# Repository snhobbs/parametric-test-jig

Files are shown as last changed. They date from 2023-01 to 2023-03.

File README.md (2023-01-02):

# parametric-test-jig

*Parameterized OpenSCAD projects allowing single command generation of probe stations.*

## Purpose & Philosophy
Probe stations typically have many parts that need to line up exactly with several different parts.
+ PCB under test pads must line up with the probes
+ Probes must lineup with a base PCB or be wired.
+ Pressure pins have to miss components
+ PCB supports must not interfere with parts
+ Alignment pins need to line up with PCB mounting holes
+ The entire stack needs to have the correct vertical spacing with mounting holes that line up.

Typically only high value designs end up with a test jig. They are relatively complicated
and time consuming, requiring investment to make one. Managing several becomes a real support task.
The complexity leads to changing the design to simplify the test jig. The description of the jig is
simple: test probe bed of nails that lines up with the board but the development is long and fiddly.
The purpose of this project is to make a jig from that description. While you wait for boards to be delivered
use this project to have a probe station ready by the time they come in.

Time is burned during bring-up
that could be solved with a jig but it isn't available until much later.
The aim of this project is to make it easy to start each project with a development
jig at your elbow. Ideally designs can be related, allowing jigs to be reused when the designs are derivative.
This project focuses on making updates to a large body of related projects as simple as possible.

+ While designing your board plan the tester. This will help ensure appropriate testing is possible
+ Compile the jig from your design with minimal effort
+ Get both board and jig in at similar times, allowing development and debug to take advantage of the testing infrastructure. As the test has to be designed why not benefit from that work earlier?

## Applications
+ Manufacturing test
+ Programming station
+ Simplify connections to a development board.

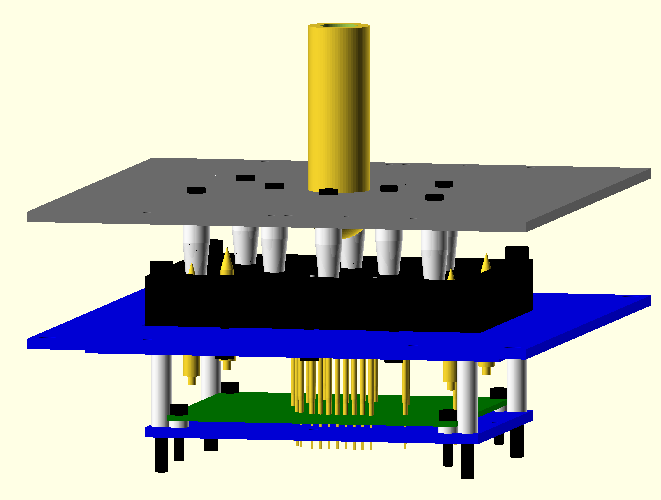
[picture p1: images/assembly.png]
Cassette + Pressure Plate Assembly

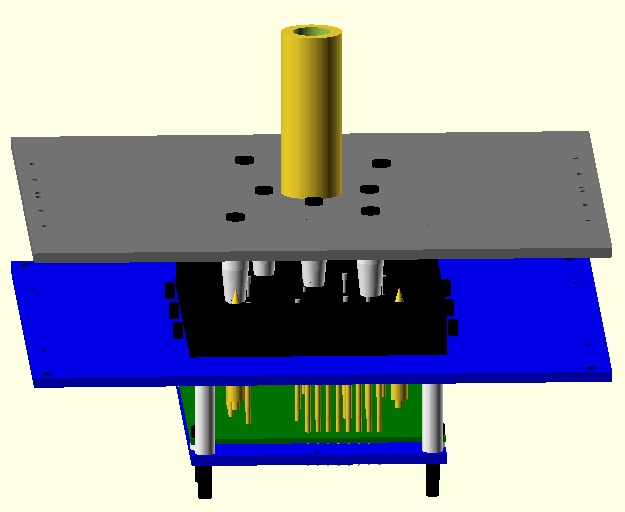
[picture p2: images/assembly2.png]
Cassette + Pressure Plate Assembly

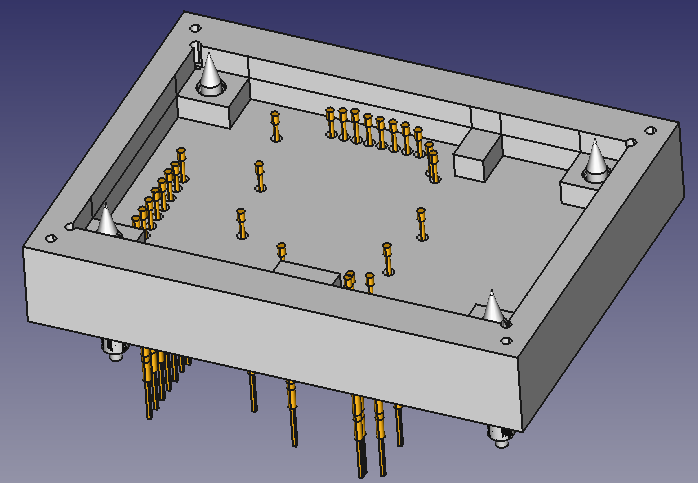
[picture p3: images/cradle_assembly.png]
Cradle Assembly


## Features
+ Create a test probe or pogo pin adapter to a PCB design with as little trouble as possible
+ Minimize duplicated effort when creating a test design
+ Allow a parameterized model that is easily updated to the master version.
    + Have no modifications to the generated sections, allowing updates without needing hand work
+ Allow resue of mechanical sections and mechanical designs
+ Exactly place parts to ensure they will correctly mate with other mechanical sections and PCBs.
+ Single command generation of manufacturing documentation
+ Libraries of parts available for reuse

## Description
The current version has a single jig structure as the target. A 3D printed (or machined) part holds the probes & alignment pins, supports the PCB, and has integrated mounting holes for connecting the other sections. The pin end of th probes are soldered into a base PCB which is mounted to a base plate which inturn is connected to the cradles mounting screws. This all fits in a standard aliexpress test jig press.

This design centers around the cradle as the main holder of complexity. That can be placed into any number of assemblies with a new assembly.scad design.

A Makefile allows all units to be exported for manufacturing with a single command.

This project works with kicad-testpoints and kicad-parts-placer to pull data from a kicad design and generate a test pcb and the jig.

## Test Jig Press Generated Sections
| Type | Manufacturing Process | Description |
|---|---|---|
| Base plate | Laser cut | Mechanical mount for the testing PCB |
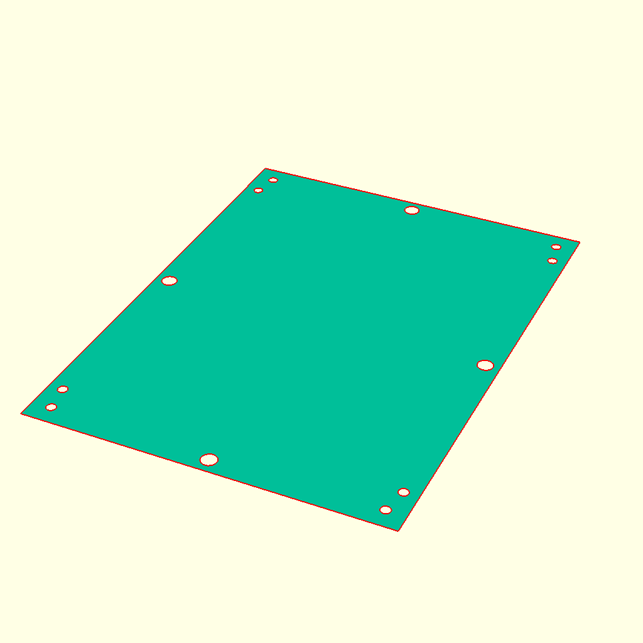
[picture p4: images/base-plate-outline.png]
||| |
| Support plate | Laser cut | Mechanical mount on the jig chassis. This supports the cradle.
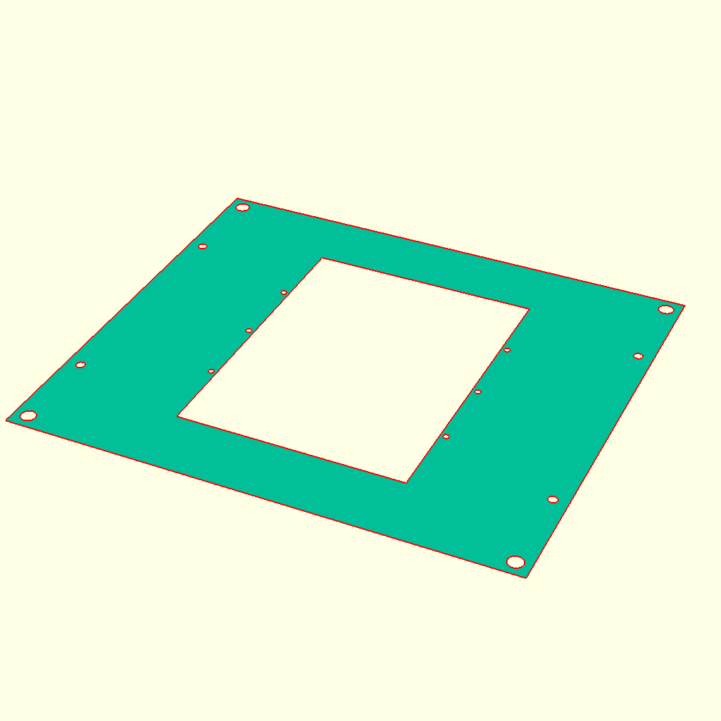
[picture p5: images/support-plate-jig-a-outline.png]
||| |
| Support plate + Base plate | Laser cut | Mechanical mount on the jig chassis. This supports the cradle.
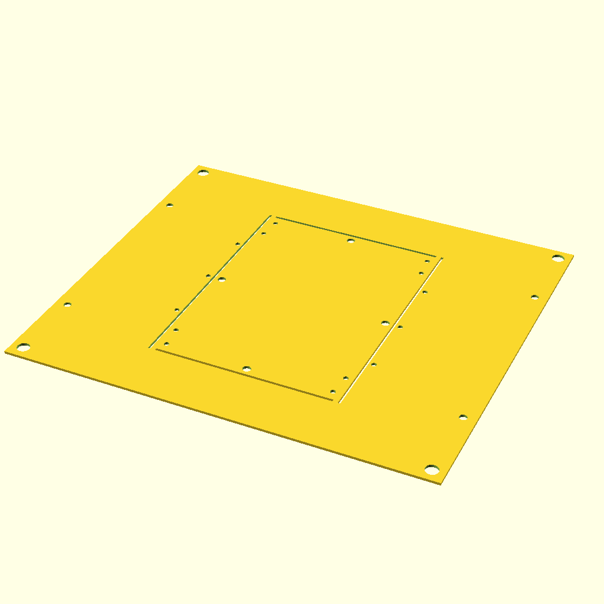
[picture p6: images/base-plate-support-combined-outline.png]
||| |
| Support bracket | Laser cut | Bracket that screws into the support plate that the cradle sits on. This part is added to allow the cradle to be taken in and out after the pins have been soldered |
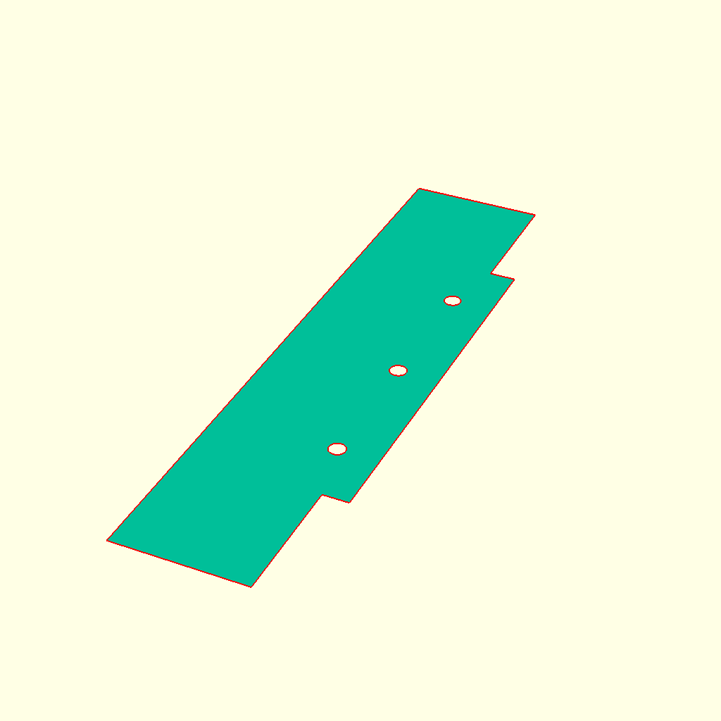
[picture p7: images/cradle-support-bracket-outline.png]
||| |
| Pressure plate | Laser cut |Plate with pressure pins mounted which compresses the board. Pin placement is done to ensure the pins evenly compress the board without interfering with parts.
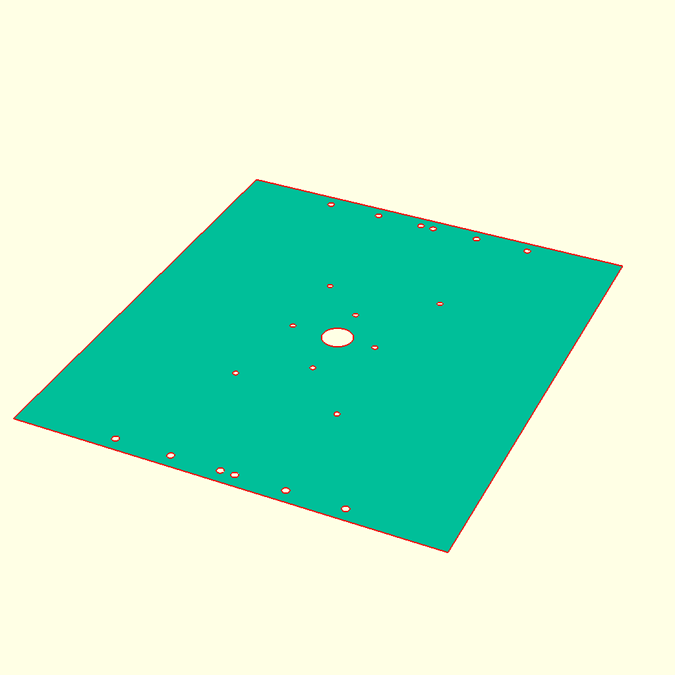
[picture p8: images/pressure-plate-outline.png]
||| |
| Cradle | 3D printed/machined | Support for the design under test, guide for placement over alignment pins, holder of the probes, mechanical support for cassette assembly. |
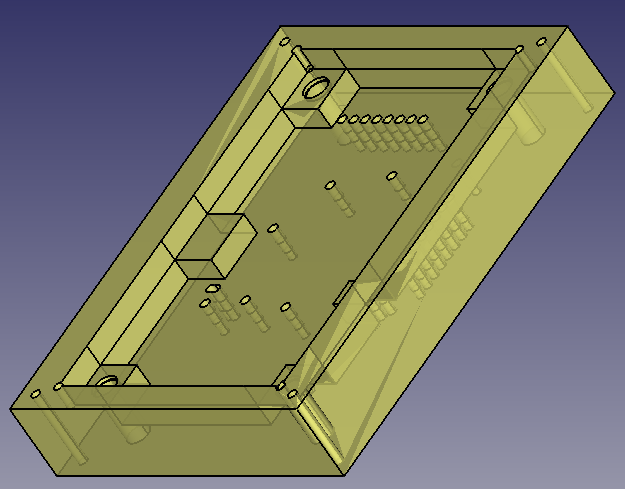
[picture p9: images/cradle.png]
||| |

## Workflow
### Starting a new project
1. Design the PCB with testing in mind, introducing testing later is expensive. Aim to have probes on only one side of the board. Choose the test point size and spacing to match the probes you intend to use. Prefer a single probe pitch.
2. Generate a list of test points and alignment pins matching the format of the example. 
3. Run the openscad generator on the list to generate the openscad source file of probes and alignment pins.
4. Edit the design.scad file to add supports and to define the board characteristics

+ List of probes
    + Define by hand
    + Use kicad-testpoints + dataframe_to_scad
    + Use a centroid file + dataframe_to_scad
+ Support pins
+ Pressure pins
+ DUT model (as stl or defined in a module)
+ Test PCB model (as stl or defined in a module)
+ setup-shell-environment.sh with path setting to libraries 
+ Customization settings
    + Support outline
    + Board clearance outline
+ Submodule parametric and change the path to objects in the makefile and the path in setup-shell-environment.sh

## Reach Goals & V2.0.0 Features
+ Check parts clearance
    + Check for clearance between objects and features such as the separation between a pogo and a support pillar
+ Auto input of a board outline for the cradle

## References
+ Inspired by ['OpenSCAD ATE generator'](https://github.com/5inf/TestPointReport2STL)
+ <https://www.sculpteo.com/en/tutorial/openscad-prepare-your-model-3d-printing/openscad-user-interface/>
+ <https://mastering-openscad.eu/>
+ <https://github.com/ultimachine/Test-Jig>
+ <https://github.com/fossasia/pslab-test-jig>
+ <https://github.com/wntrblm/Hubble>
+ <https://github.com/brianredbeard/pogo-jig>
+ <https://github.com/Erhannis/PogoPinJigGen>
+ [traditional design approach videos](https://youtube.com/playlist?list=PLWx_0HhFuM-5BIxH8N3SzQfybV2INpMgL)

+ Similar project: <https://github.com/mdeweerd/openfixture>, <https://github.com/tinylabs/openfixture>, <https://tinylabs.io/openfixture/>

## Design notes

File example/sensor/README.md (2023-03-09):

+ Each section imports the design
+ Design modules etc. only used for a single model are only in the corresponding models directory

+ cradle should be able to plug into various types of jigs
    + Needs enough mounting holes

+ For building, designing, and exporting without confusion (WYSIWYG) have a file for each object concept with no design dependancies.
    + In the assembly or sub assembly have a module with no inputs which makes a concrete object. This is then called in another file to allow exporting.
    + a concrete file should have a single use statement and a single module call.
    + When more than a single concrete object is desired, make a seperate file
+ For parts that can be 2d the assembly should extrude the part with the top level module being the projection.

## Module Naming
    + top level modules have no arguments, are centered at 0,0, named the object
    + Creation templates are wrapped by a top level module to set the config data
        + These are named make_*
    + Other modules can be named however following a decent style code

## Manuafacturing
    + Export the 2d and 3d models with a make file
    + Each object has a translation unit that we can call
    + The 2D parts will be milled or laser cut
    + Find ways of putting parts in parts, merge the pcb baseplate and the support plate

TODO
    + Add generation of design file from config

## Build
+ Break parts into categories of 3d and 2d parts, compile the matching types

+ For customization all variables need to exist in the top module

## File types
+ Top level: Intended for use with a customizer, breaks settings out to abstractions
+ Abstraction: Expresses the idea of a part without holding the concrete data.
+ Object: Calls a top level module only, allowing a part to be created
+ Assembly: Brings together inter related designs. Objects call modules in this to make objects.

## Reuse
+ Sections that are to be reused need to have the data pertaining to them broken off to a standalone module.
+ Tool sets can be used but should be minimized to describe the part as simply and in as stand alone manner as possible.
+ Would like more interchangable parts so the cradle should be the same size if possible

+ If the cradle size is the same for different boards then only the cradle needs to be replaced

+ Pressure pins are mirrored relative to board position like the probes
+ Add pressure pin positions to the PCB on a drawing label with the correct radius, this will help avoid interferace.
    + There are only a few pressure pins so these are chosen by hand.
    + One option is using a large grid and assembling as needed.
        + 5mm seems to be good, choose the location on the resulting grid
            + Use drill press for this?

+ Standard libraries are added to the OPENSCADPATH, these are submoduled
+ Add a shell script with the OPENSCADPATH that can be sourced
+ soft link or copy the assembly and cradle_assembly files
+ Set the construction type with the OPENSCADPATH

+ setup environment by adding setup-shell-environment.sh setting OPENSCADPATH
+ run source setup-shell-environment.sh && make all -j${nproc --all}
+ To run openscad normally with the assembly the press-jig files can be softlinked in (ln -s press-jig-type-a/* ./). This will work identically as adding press-jig-type-a to the path. The path to the library will still need to be included. The assembly in the library can also be used as the path is set.

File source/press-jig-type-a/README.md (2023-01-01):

# Press Jig Type A
+ 150x170 mm plate
+ Defined by the placement of the clamp, top & bottom fasteners

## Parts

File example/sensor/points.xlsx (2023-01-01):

source ref des | test point ref des | pad name | pad number
TP1 | TP1 | 1 | 1
TP2 | TP2 | 1 | 1
TP3 | TP3 | 1 | 1
TP4 | TP4 | 1 | 1
TP5 | TP5 | 1 | 1
TP6 | TP6 | 1 | 1
TP7 | TP7 | 1 | 1
TP8 | TP8 | 1 | 1
TP9 | TP9 | 1 | 1
TP10 | TP10 | 1 | 1
TP11 | TP11 | 1 | 1
TP12 | TP12 | 1 | 1
TP13 | TP13 | 1 | 1
TP14 | TP14 | 1 | 1
J4 | TP15 | 2 | 2
J4 | TP16 | 3 | 3
J4 | TP17 | 4 | 4
J4 | TP18 | 5 | 5
J4 | TP19 | 6 | 6
J4 | TP20 | 7 | 7
J4 | TP21 | 8 | 8
J4 | TP22 | 9 | 9
J2 | TP23 | 2 | 2
J2 | TP24 | 3 | 3
J2 | TP25 | 4 | 4
J8 | TP26 | 1 | 1
J8 | TP27 | 2 | 2

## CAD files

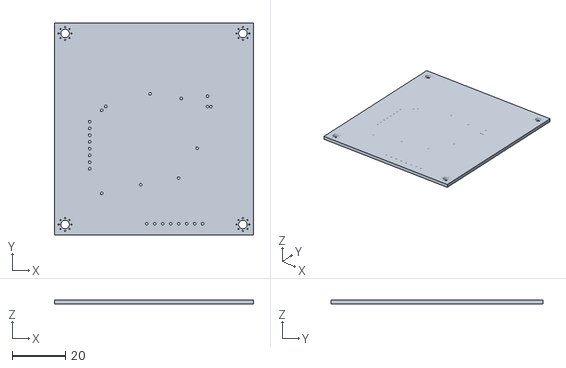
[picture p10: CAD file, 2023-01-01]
example/sensor/test-board-pcb.stl
75.0 x 80.0 x 1.60

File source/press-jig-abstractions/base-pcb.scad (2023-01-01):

module make_base_pcb_outline(size, holes) {
    difference() {
        square(size, center=true);
        for(hole=holes) {
            translate(hole[1])circle(d=hole[0]);
        };
    };
};

base_pcb_outline();

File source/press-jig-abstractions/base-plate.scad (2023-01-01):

module make_base_plate_outline(size, holes) {
    difference() {
        square([size.x, size.y], center=true);
        for(hole=holes)translate([hole[1][0], hole[1][1], 0])circle(d=hole[0]);
    };
};

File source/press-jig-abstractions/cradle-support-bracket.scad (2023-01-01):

/*
    Support bracket recradletangle made of 2x rectangle, one for mouting to the base, one for the overhang
        + mounting size
        + support size
    Centered on the overhang beginning
*/
module get_support_bracket_outline_base(mounting_size=[10, 10], support_size=[6,4]) {
    union(){
        translate([-mounting_size[0]/2, 0])
            square([mounting_size[0], mounting_size[1]], center=true);
        
        square(support_size, center=true);
    };
};

module make_holes_2d(holes){
    for(hole=holes) translate(hole[1])
        circle(d=hole[0]);
};

module make_support_bracket_outline(mounting_size=[10, 10], support_size=[6,4], holes=[]) {
    difference() {
        get_support_bracket_outline_base(mounting_size=mounting_size, support_size=support_size);
        make_holes_2d(holes);
    };
}

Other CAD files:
source/press-jig-abstractions/cradle.scad
example/sensor/alignment-pins.scad
example/sensor/cradle.scad
example/sensor/design.scad
example/sensor/pressure-pins.scad
example/sensor/probes.scad
source/press-jig-abstractions/design-under-test-pcb.scad
source/press-jig-type-a/assembly.scad
source/press-jig-type-a/cradle_assembly.scad
source/press-jig-type-a/objects/assembly.scad
source/press-jig-type-a/objects/base-pcb-outline.scad
source/press-jig-type-a/objects/base-plate-outline.scad
source/press-jig-type-a/objects/base-plate-support-combined-outline.scad
source/press-jig-type-a/objects/cradle-support-bracket-outline.scad
source/press-jig-type-a/objects/cradle.scad
source/press-jig-type-a/objects/cradle_assembly.scad
source/press-jig-type-a/objects/design-under-test-pcb-outline.scad
source/press-jig-type-a/objects/pressure-plate-outline.scad
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

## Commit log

2023-01-02 adding design configuration options to support bracket
    [assembly.scad, design.scad]
2023-01-02 shrinking cradle overhang
    [design.scad]
